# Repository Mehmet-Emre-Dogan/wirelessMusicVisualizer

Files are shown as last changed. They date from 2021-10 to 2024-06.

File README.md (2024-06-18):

# wirelessMusicVisualizer
Using two node MCU ESP8266 modules and addressable RGB LED strip, visualize the music, display animated flags, brighten the darkness (with the help of torch and emergency torch modes), and even Adalight compatible. Therefore, you can use it with any kind of Adalight compatible software, such as [Prismatik Unofficial](https://github.com/psieg/Lightpack)

# Abstract
**Purpose**: Measure the voltage level of the sound output of a device, i.e., computer, and send it to the receiver LED module via UDP protocol to visualize music.

## **Features**:
- Ability to change the used wi-fi channel to keep away interference
- Capable of saving the current configuration to external I2C EEPROM to avoid adjusting the settings on each boot
- Different colors and visualizing modes
- Software restart mode for transmitter
- Very low latency (no noticeable lag even with listening to music with wired headphones)
- Analog or serial data acquisition

## **Other Operating Modes**:
- Flag colored flowing light
- Ambiance light changing color according to the seen video on the computer screen
- Emergency light (with different tones of white)

## **Notes**:
- Both transmitter and receiver stations’ CPU frequency is set to 160 MHz to increase stability and smoothness
- Due to the nature of the UDP, sometimes packet drops occur. If the packet drops are incredibly high, changing the wi-fi channel is required. 

# Videos & Gifs of the project
<div align="center">
demoGif
<br>
</div>
<br>
The real project looks way smoother than the gif. You may watch the YouTube videos to see that. In fact, the actual refresh rate of the project is nearly 100 Hz; however, YouTube supports only up to 60 fps, and the gif is unfortunately only 30 fps.
<br>

- Please watch the [complete demonstration video](https://www.youtube.com/watch?v=xi880eUqIho) on YouTube.
- You may also want to watch my [playlist](https://www.youtube.com/playlist?list=PLV24y8ZhNEglrx4vv8YyNaVGACWpZlcM2) consisting of uncopyrighted music visualized by this project.

# Features
## Music visualization (Transmitter required)
- Smooth bar music visualizer in different color modes (steady gradient, flowing gradient, color shifting)
- Fast bar visualizer
- Brightness changing visualizer
- Optional music indicator and seconds indicator for all modes
## Torch (Transmitter required)
- Warm white light, 2700K color temperature.
- Optional seconds indicator
## Animated flags (Transmitter required)
- Display your county's flag colors on the RGB stick
- Not music reactive
## Emergency torch mode (nothing required) 
- Various colored lights in the color range 2700K to 6500K (press the red button once to change color)
- Adjustable brightness
- Optional seconds indicator (double press the red button to enable/disable seconds indicator)
## Adalight mode (USB micro type-B to type A cable required)
- Adalight client for Adalight compatible software

# Usage
## Connection with the transmitter station
Unpress the toggle switch first, then power up. If the transmitter station is near the receiver and turned on, the receiver will connect to the transmitter automatically and run according to the transmitter's configuration. 

## Audio sources for the transmitter station
### Analog
- Connect the 3.5mm audio jack to the audio source (PC/phone/tablet etc.) via y-splitter cable
- Select source as `analog` at the menu
### Serial
- Connect the transmitter station to a PC via USB cable.
- Install a client ( example: https://github.com/Mehmet-Emre-Dogan/vu-meter-with-serial ) to the PC to passthrough the audio signal from PC speaker/microphone to the transmitter station
- Select source as `serial` at the menu

## Enabling Adalight client mode
Press the toggle switch, adjust the potentiometer knob to the maximum, then power up the receiver. If you see the red, green, blue colors, respectively, the Adalight client mode has been initialized successfully.

## Enabling emergency torch mode
Press the toggle switch, and adjust the potentiometer below the maximum value, then power up. Note that the potentiometer is software inverted in the emergency torch mode so that the brightness increases when the potentiometer is rotated clockwise. (I did this because I was lazy to open the box again and swap the potentiometer positive and ground connections by desoldering and resoldering. I need to do the soldering job again because the purple cable has a jumper pin, but the blue one does not. The cables mentioned above can be seen on the image titled [Receiver station lid](#receiver-station-lid) ) 

## Changing modes
To your mode selection be valid, you need to restart the receiver station after adjusting the switch and the potentiometer. To restart, simply cut the power off and then back on.

## Browsing through the menu & changing the parameters
When the menu item title is highlighted, rotating the rotary encoder will change which setting you are about to change.
When a variable is highlighted, rotating the encoder will change the value of the variable.
Pressing the rotary encoder button will swap the selected item. For example, when the 'Brightness' is selected, if you press the encoder button, the brightness value will be selected to adjust the brightness of the LEDs.

## Saving the configuration
When you adjust the settings, move to 'saveConfig.' on the menu and press the rotary encoder button to write your current configuration to the external EEPROM.

# Necessary Libraries
Please install the libraries below if you have not done yet.
- [Fastled library](https://github.com/FastLED/FastLED)
- [Adafruit GFX library](https://github.com/adafruit/Adafruit-GFX-Library)
- [Adafruit SSD1306 library](https://github.com/adafruit/Adafruit_SSD1306)
- [SoftwareI2C library](https://github.com/Seeed-Studio/Arduino_Software_I2C)

# Schematics
## Transmitter
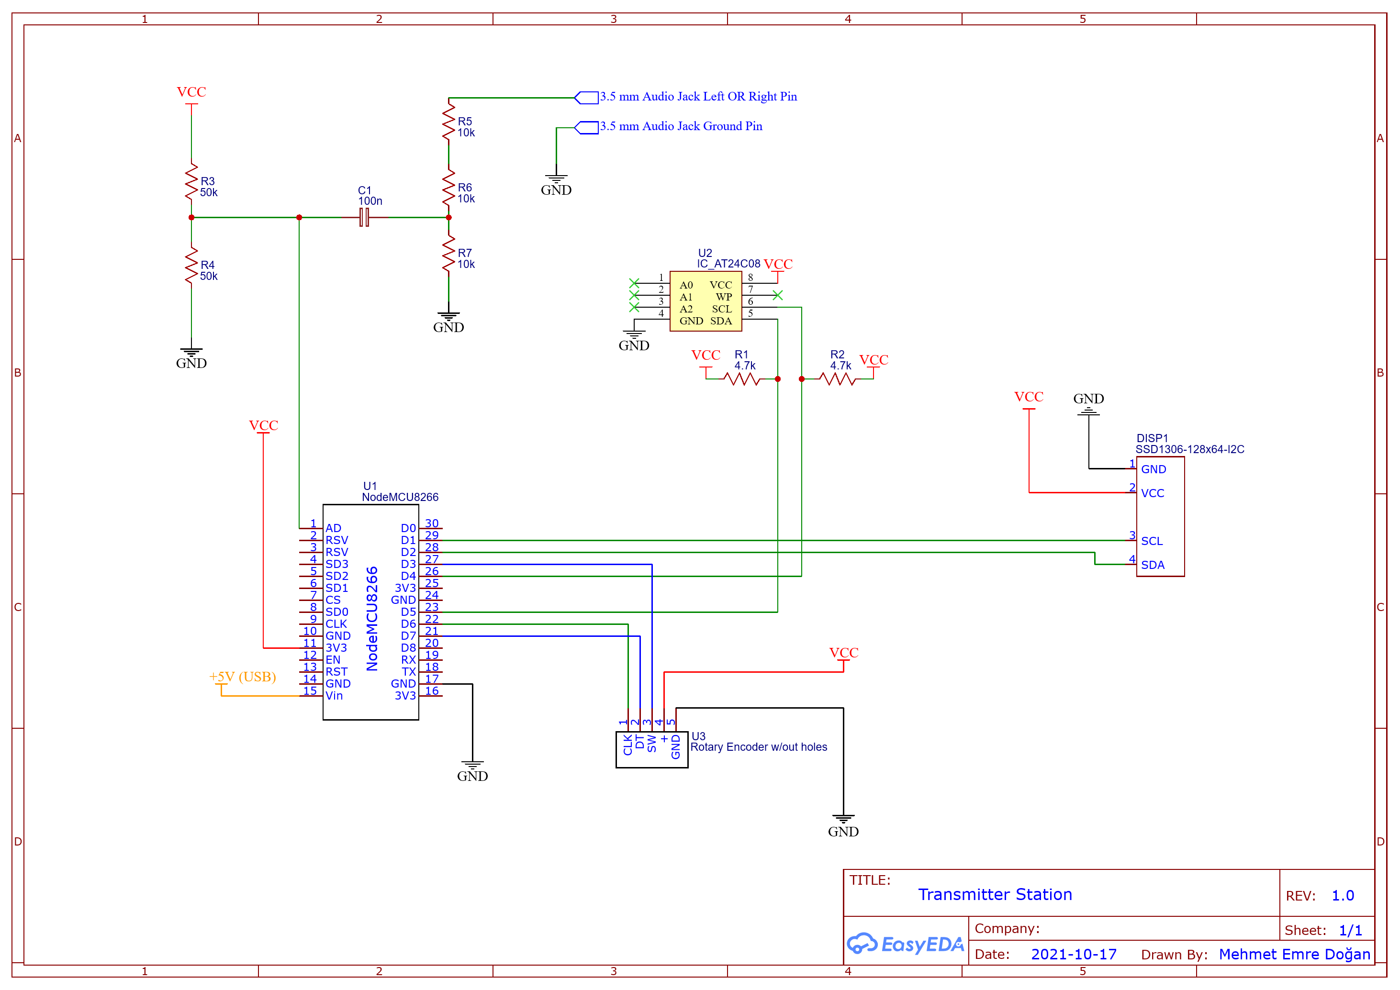
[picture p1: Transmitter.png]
Transmitter Schematic


## Receiver
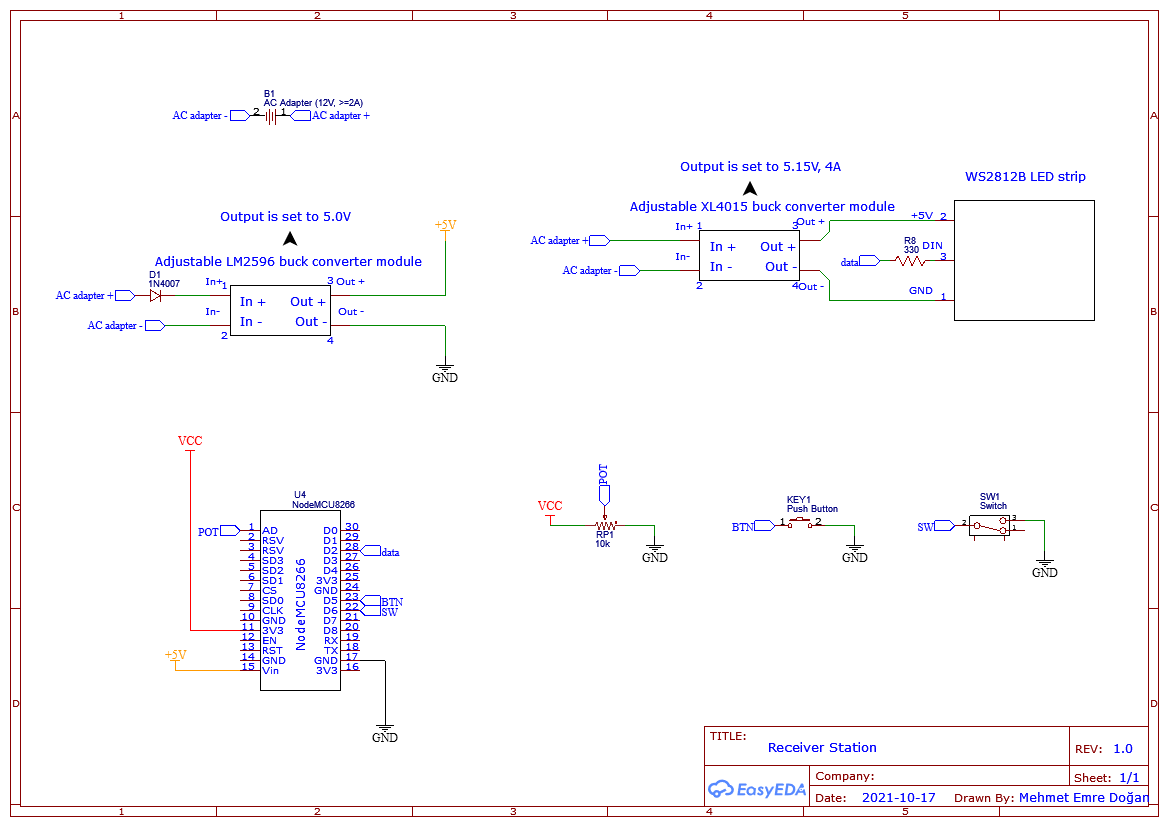
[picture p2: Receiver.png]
Receiver Schematic


# Pictures

## Transmitter
### Inside of the transmitter station
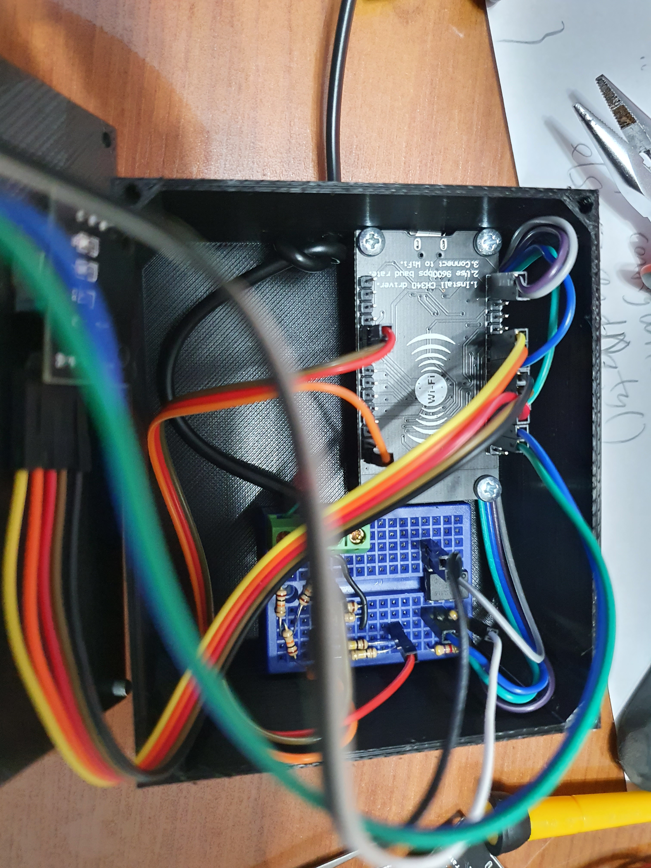
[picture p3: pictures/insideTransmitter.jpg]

### Transmitter station lid
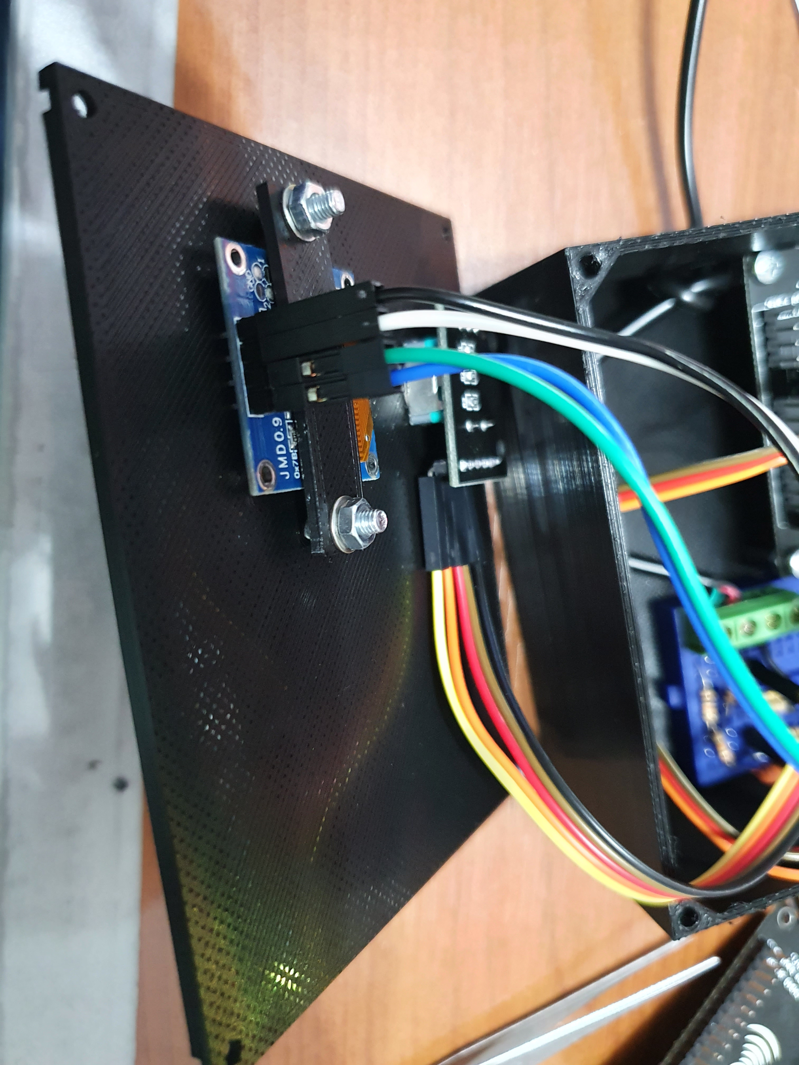
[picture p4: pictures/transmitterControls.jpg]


## Receiver
### Inside of the receiver station
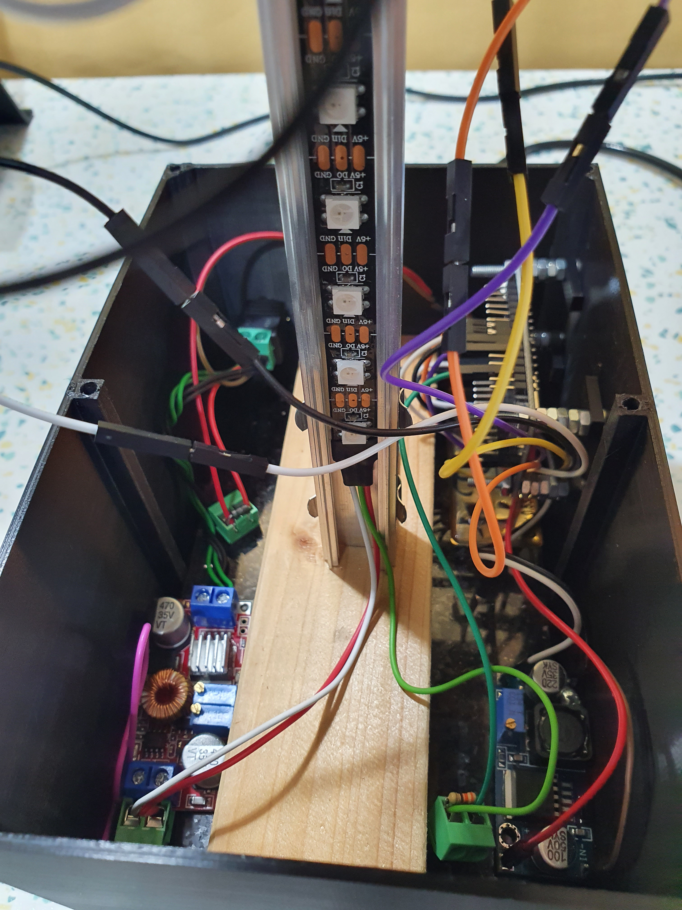
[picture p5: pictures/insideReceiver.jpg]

### Receiver station lid
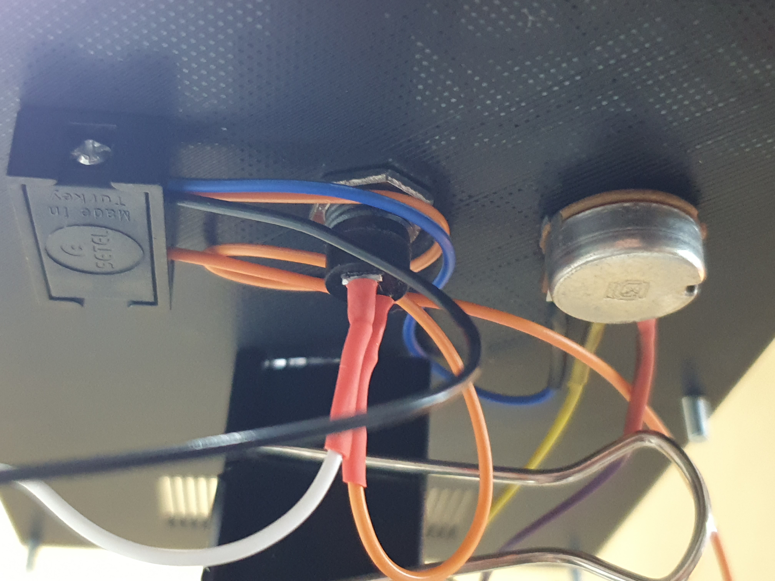
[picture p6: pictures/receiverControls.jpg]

### Adjustable XL4015 step down converter module
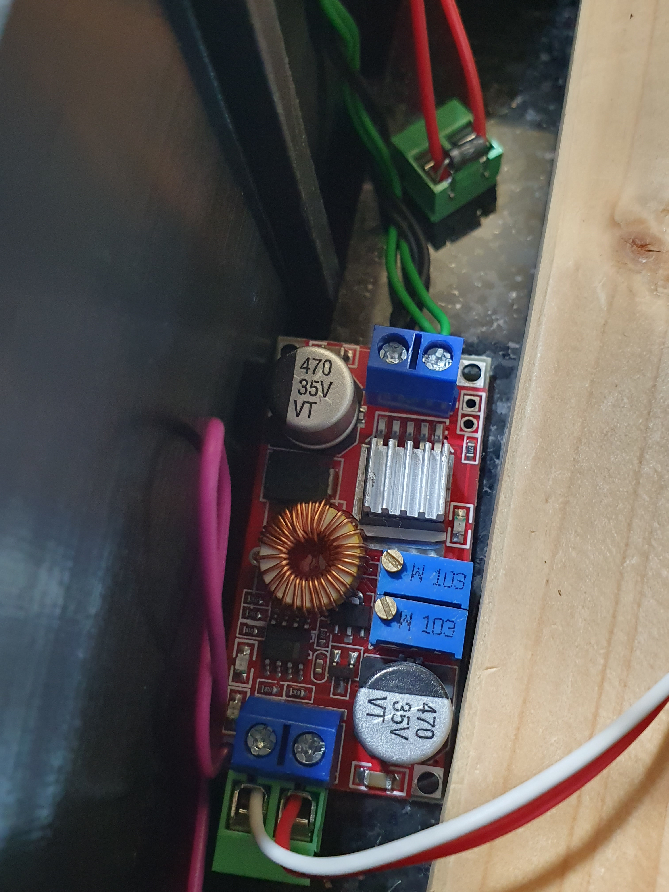
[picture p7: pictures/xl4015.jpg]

### Adjustable LM2596 step down converter module
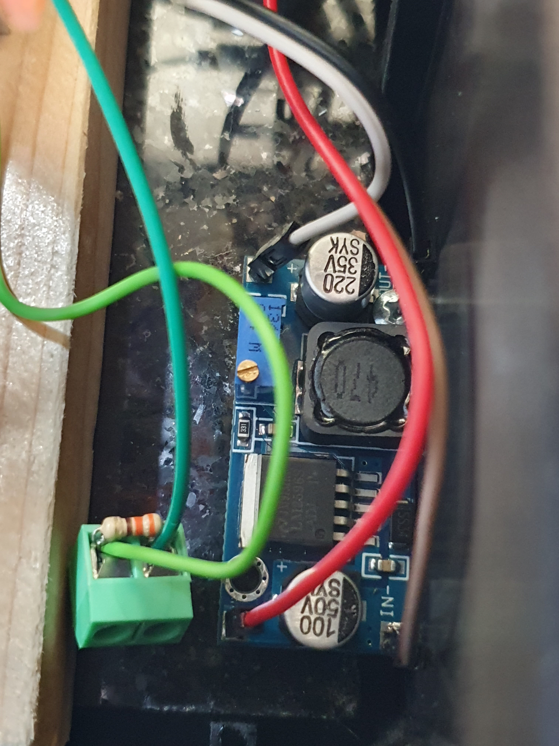
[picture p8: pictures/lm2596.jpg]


# Additional equipments
They are not directly related to the project. However, they are worth mentioning.

### Powering the device mobile or in mains power loss & failure
When necessary, the external boost converter module can be used to power the device via a power bank or any device that is powerful enough and has a USB out. Warning: You may need to decrease the brightness of the LEDs if your power gadget is not capable enough to run the device flawlessly. Most of the time, if you try to draw more current than your power gadget can handle, your power gadget will disconnect its battery from the output, and you will need to restart your power device. Sometimes, your power device can automatically do this restart process and cause the LEDs to flicker/blink. Therefore, if you face any abnormal behaviors like above mentioned, my advice is to decrease the brightness first (from the transmitter module or the potentiometer, in emergency torch mode) and then turn off and on the receiver station using the switch on the external boost converter module or directly plug out the USB cable and plug it in back.

### External XL6009 adjustable step-up converter module
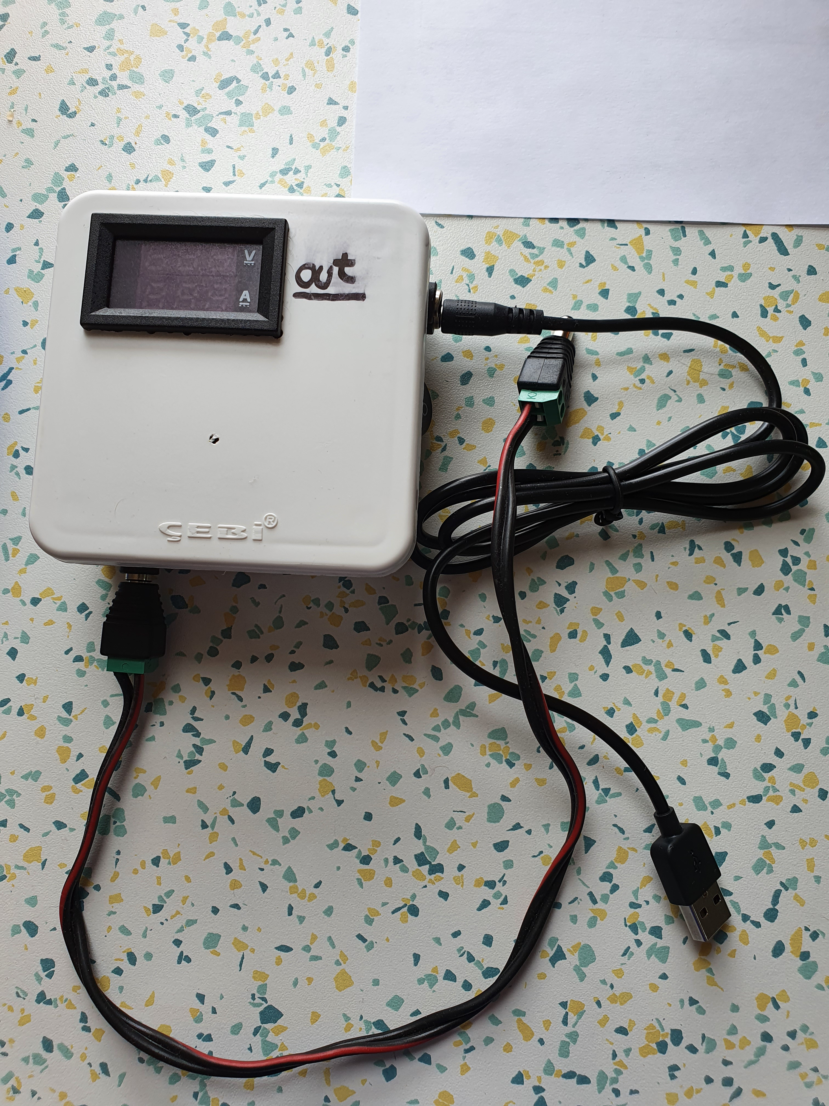
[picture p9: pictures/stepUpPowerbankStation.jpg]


### Inside of the adjustable XL6009 step-up converter module
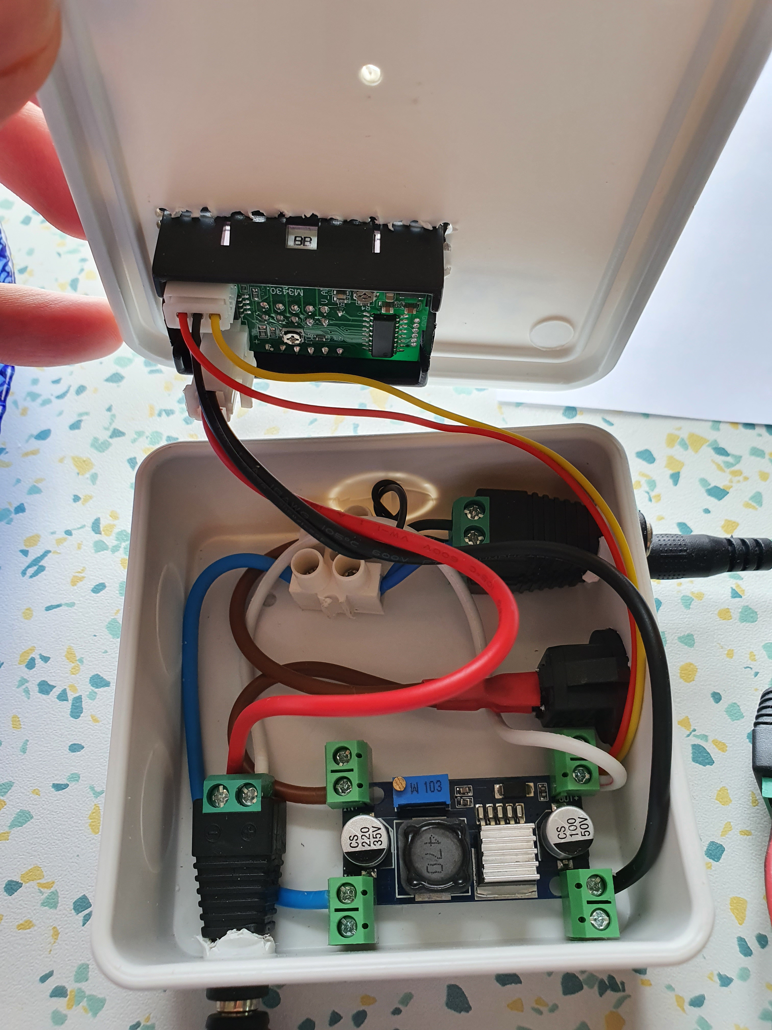
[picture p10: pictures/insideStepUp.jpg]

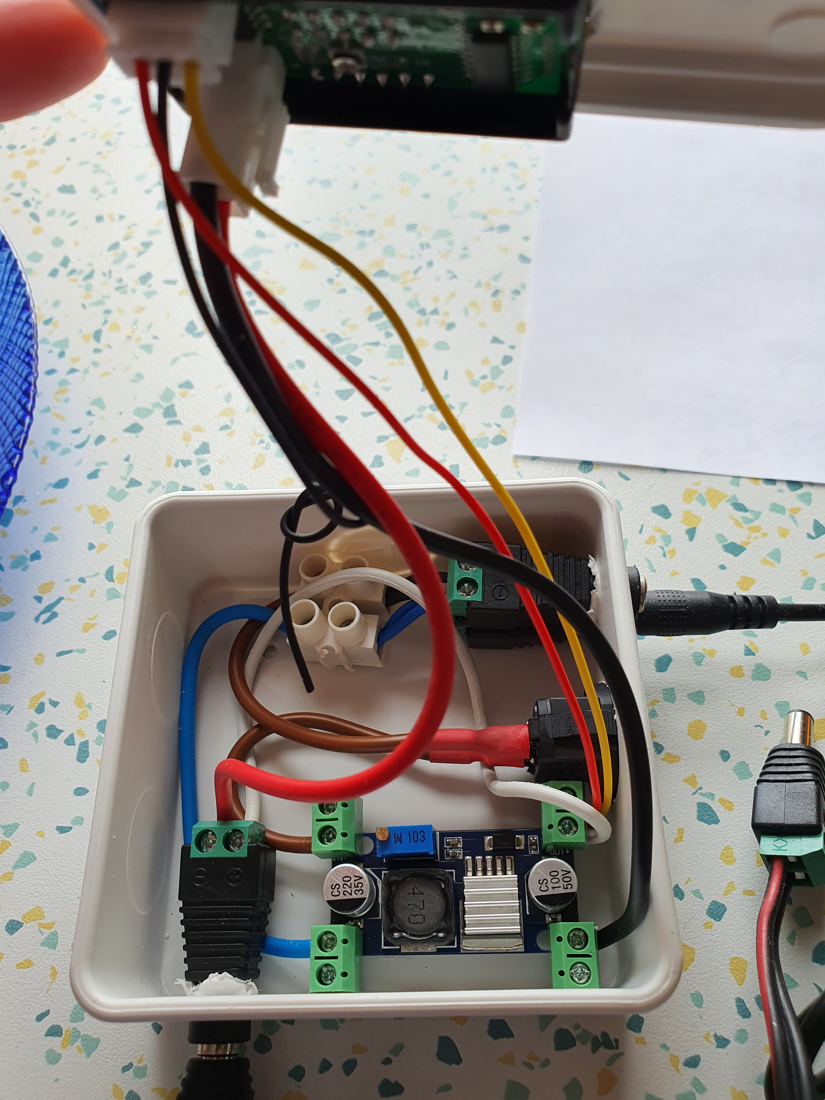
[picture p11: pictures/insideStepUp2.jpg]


### Input side of the adjustable XL6009 step-up converter module
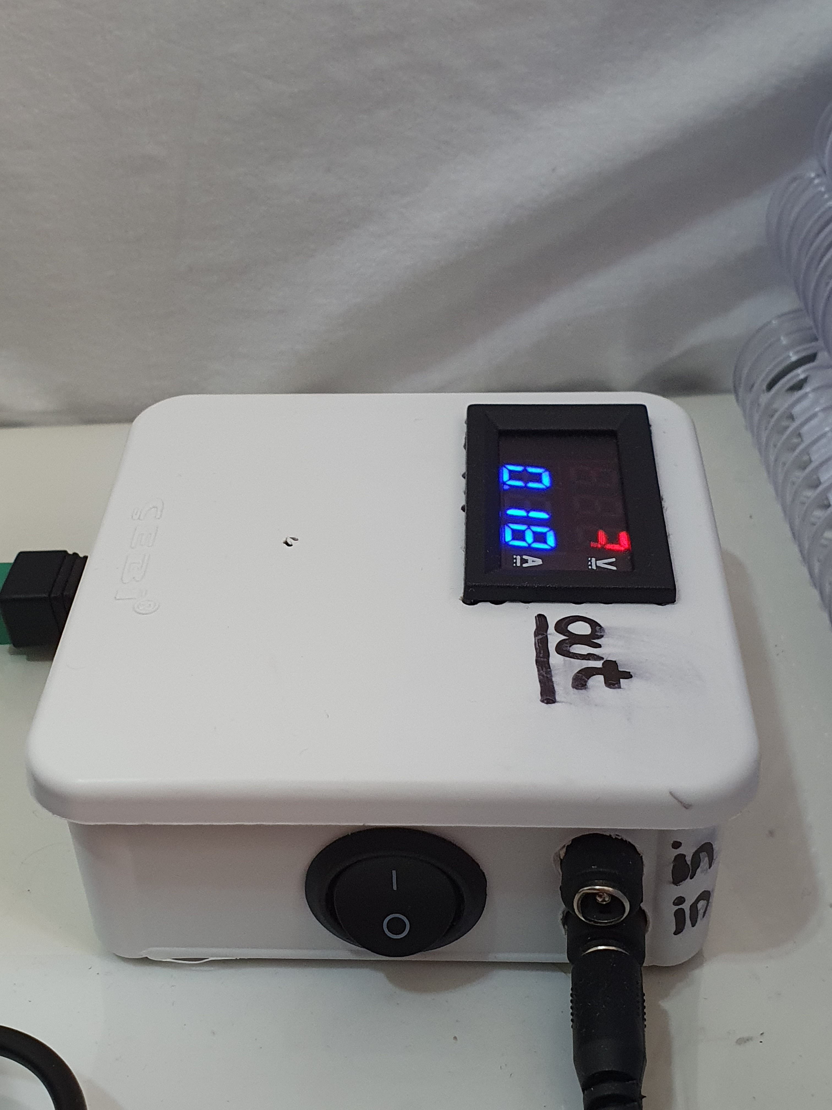
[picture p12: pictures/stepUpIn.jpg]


### Output side of the adjustable XL6009 step-up converter module
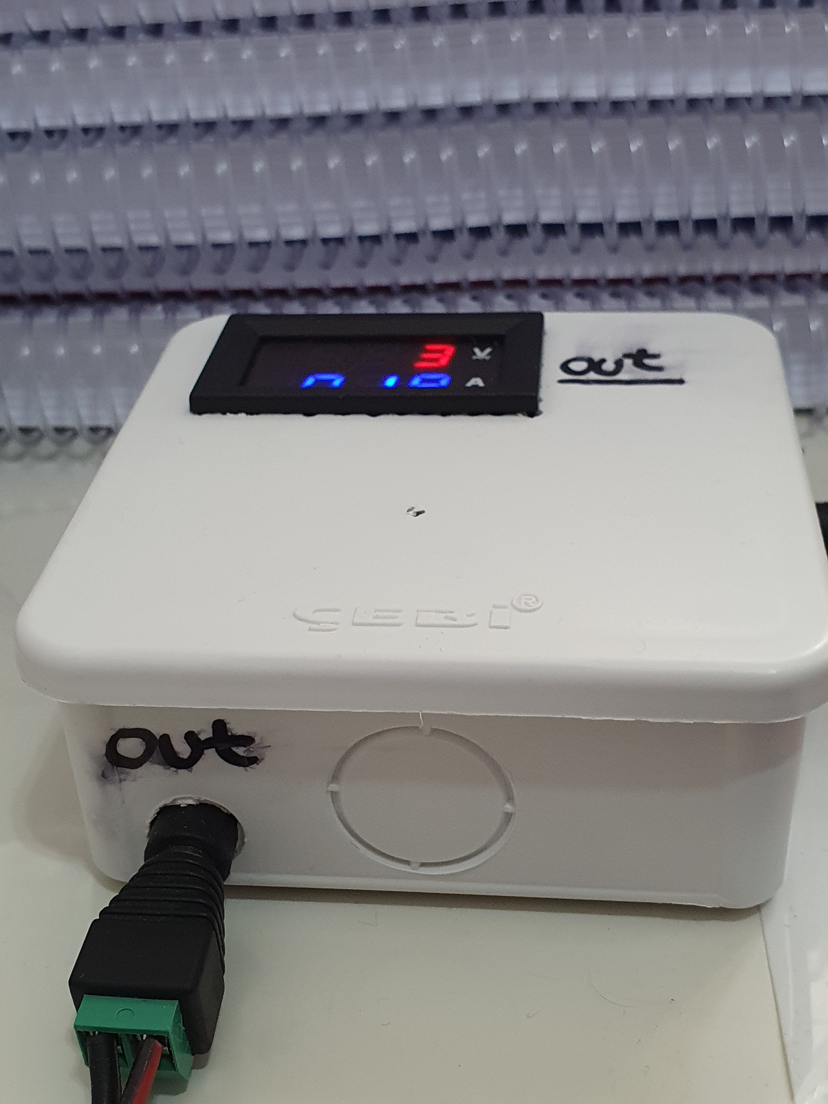
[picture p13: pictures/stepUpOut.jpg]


### Running on powerbank
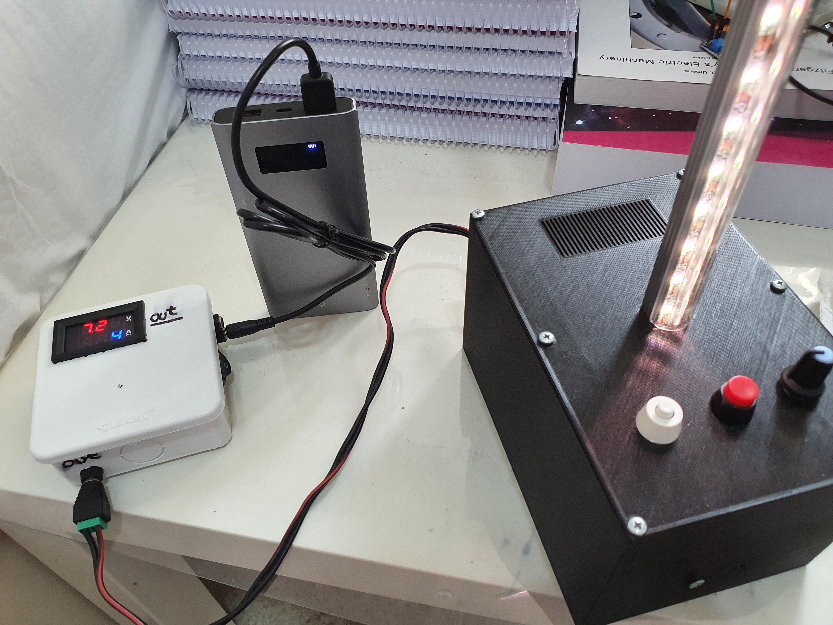
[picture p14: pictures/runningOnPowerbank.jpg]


### Attached voltmeter ampermeter combo device
Since the meter screen is multiplexing the seven-segment displays, in the above photos, the screen seems corrupted. However, this is not the case. By the way, with the naked eye, this multiplexing is not noticeable as expected.



## Recording setup
The setup to record line output of the PC with any mobile phone.
There is a 10 kOhm resistor between any signal output channel, left or right, to mobile phone microphone input.

### Y cable to split recording setup and my project (transmitter station + headphones, which also uses another Y cable)
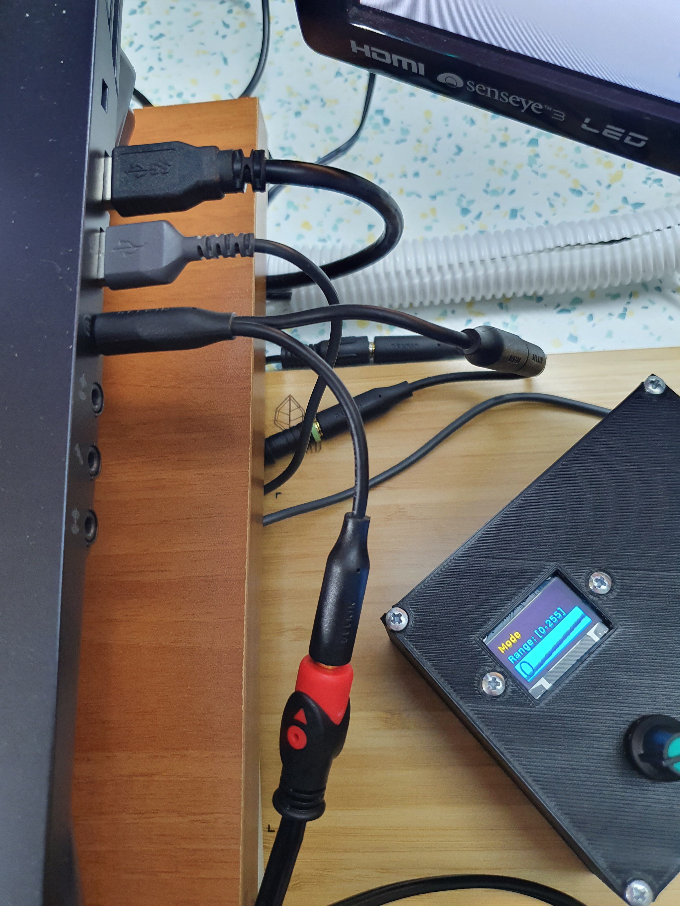
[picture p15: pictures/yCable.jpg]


### Recording setup
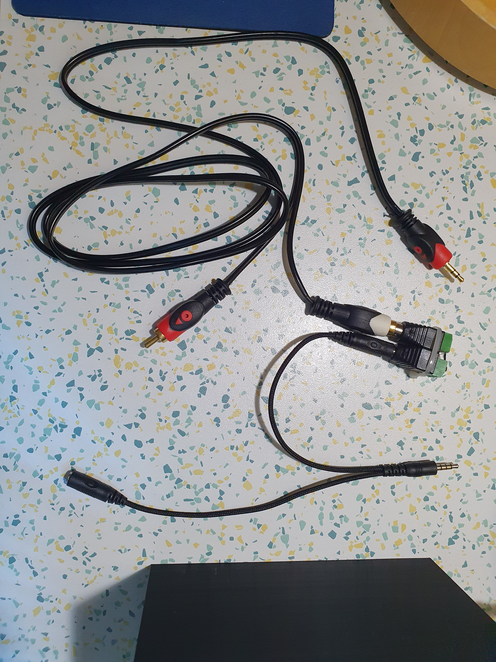
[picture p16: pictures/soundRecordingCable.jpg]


### 10 kOhm resistor close up
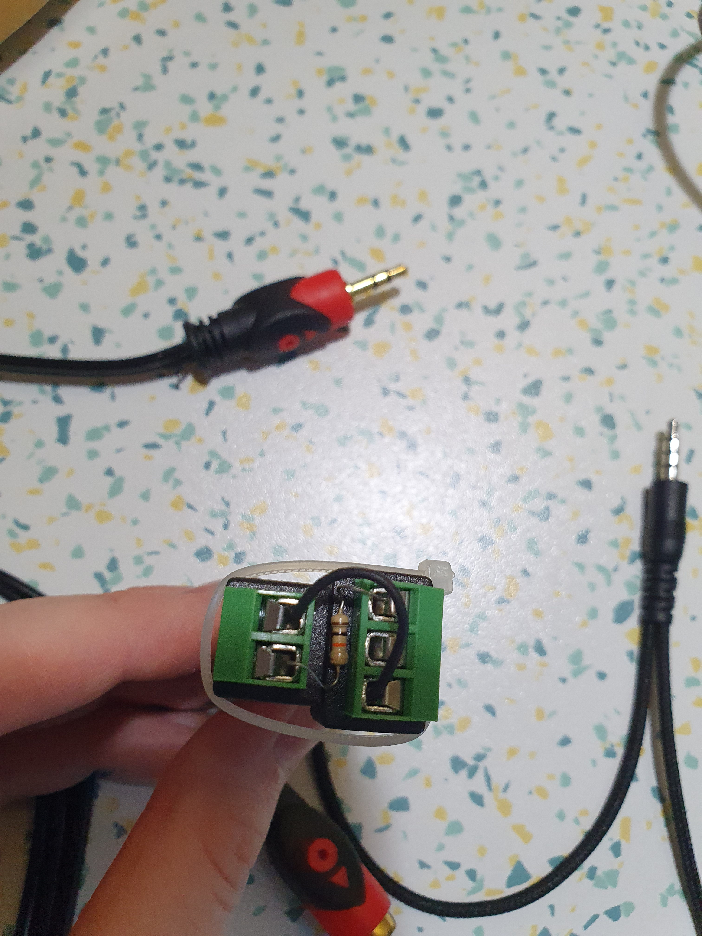
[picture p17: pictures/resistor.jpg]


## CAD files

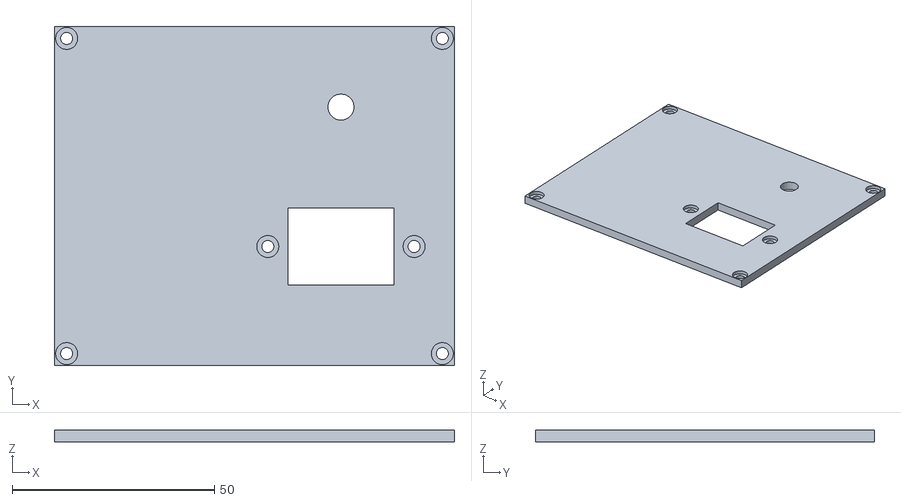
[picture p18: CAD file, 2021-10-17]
3d designs/transmitterLid.stl
99.0 x 84.0 x 3.00

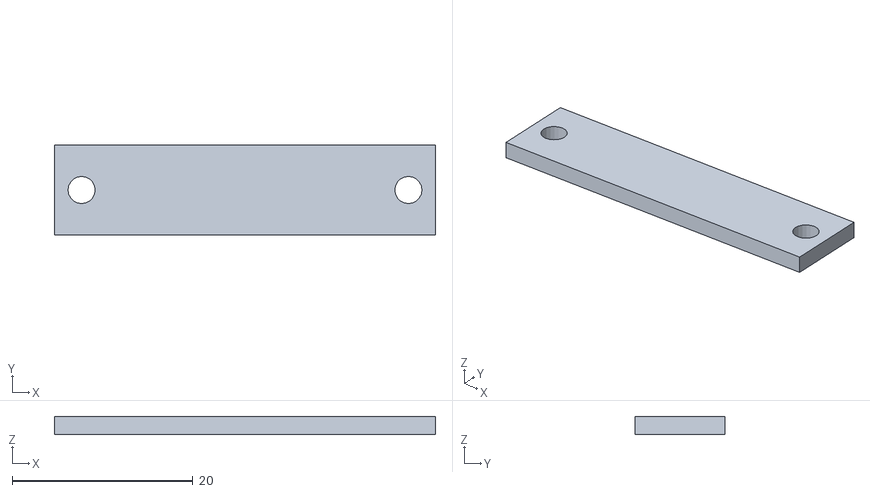
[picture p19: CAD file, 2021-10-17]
3d designs/screenApparatus.stl
42.2 x 10.0 x 2.00

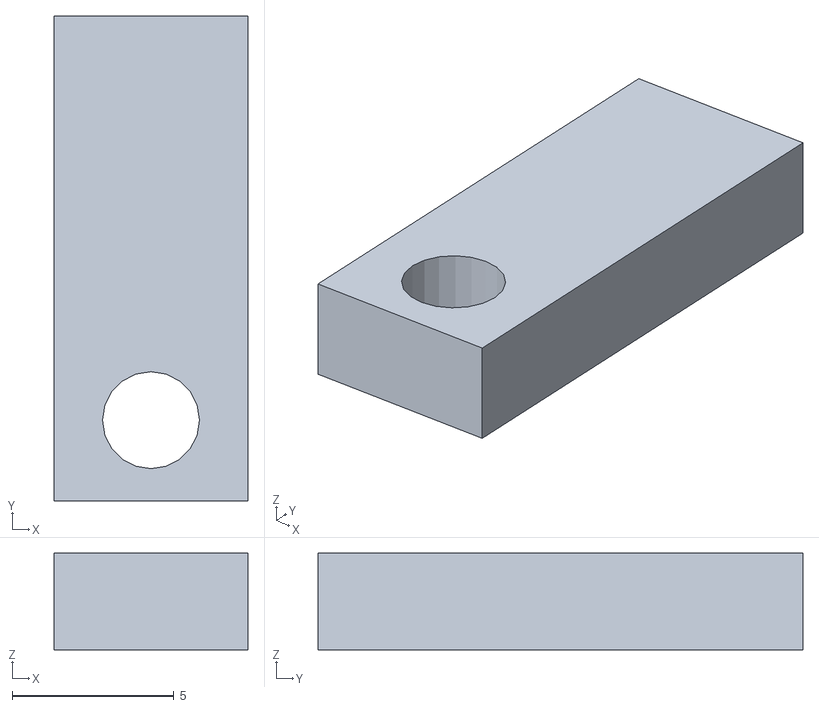
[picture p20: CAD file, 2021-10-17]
3d designs/marbleThing.stl
6.00 x 15.0 x 3.00

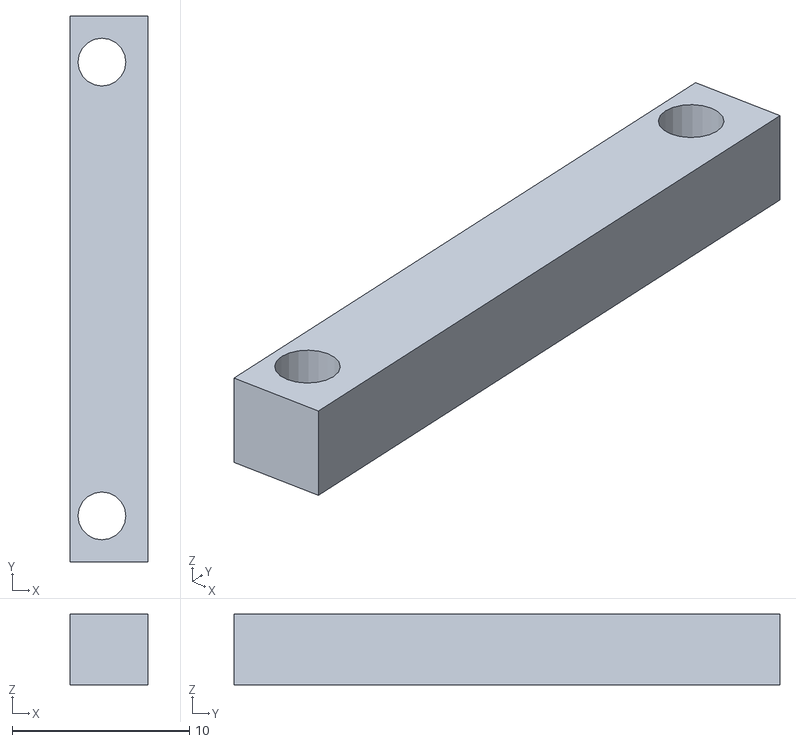
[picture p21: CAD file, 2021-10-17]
3d designs/nodeApparatus.stl
4.40 x 30.8 x 4.00

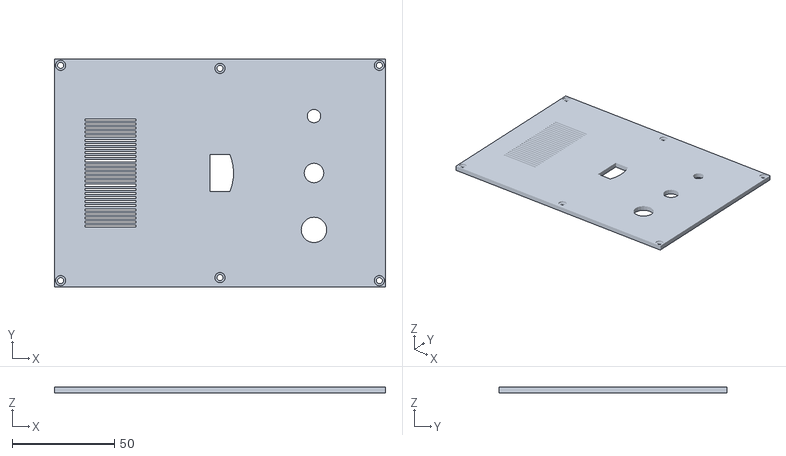
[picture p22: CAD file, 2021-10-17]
3d designs/receiverLid.stl
162.0 x 111.4 x 3.00

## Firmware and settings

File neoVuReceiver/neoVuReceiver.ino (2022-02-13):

/******** References *********/
/* 
 *  ============= Disabling wifi =============
 *  https://www.esp8266.com/viewtopic.php?p=72207
 *  
 *  ============= Animated Flag ============= 
 * https://www.youtube.com/watch?v=2owTxbrmY-s&list=PLgXkGn3BBAGi5dTOCuEwrLuFtfz0kGFTC&index=4
 * https://github.com/s-marley/FastLED-basics/blob/main/4.%20Waves%20and%20blur/phaseBeat/phaseBeat.ino
 * 
 * ============= Adalight =============
 * https://github.com/Wifsimster/adalight_ws2812/blob/master/Adalight_WS2812.ino
 * 
 */
#define FASTLED_ESP8266_RAW_PIN_ORDER
/* Libraries */
#include <FastLED.h>
#include <ESP8266WiFi.h>
#include <WiFiUDP.h>

/* Misc */
#define DEBUG_ENABLED false // Disable debug to be able to use the Adalight mode
#include "secrets.h"

/******** Constants *********/
#define EMERGENCY_TORCH_NUM 4
#define BUTTON_CONSIDERATION_LIMIT 50 // if the consequent button presses are less than it; ignore last press
#define BUTTON_DOUBLE_PRESS_TIMEOUT 120
#define BUTTON_MAX_PRESS_COU 2
#define CONNECTION_LOST_TIMEOUT 10000
#define ARRAY_SHIFT_INTERVAL 9
#define COLOR_SHIFT_INTERVAL 1

/* Display */
#define INDICATOR_OFFSET 5
#define DECAY_INTERVAL 9
#define INDICATOR_ITER_LIM 20
#define CRITICAL_LEVEL 5

/* Leds */
#define DATA_PIN D2
#define NUM_LEDS 58
#define LED_TYPE WS2812B
#define COLOR_ORDER GRB

/* Drop width modulation mode */
#define DIVIDER 6
#define MAX_WIDTH 10 //NUM_LEDS/DIVIDER
#define EMPTY_WIDTH 30
//#define DWM_MEAS_LIM 5 // Drop width modulation measurement count
#define DROP_INTERVAL 4

/* Serial communication */
#define ADA_RATE 1000000 // Baud rate for Adalight mode 
#define DEBUG_RATE 9600 // Baud rate to print debug info to computer

/* Physical ui elemets */
#define BTN D5
#define SWITCH D6
#define POT A0

/******** Function templates ********/
void ICACHE_RAM_ATTR handleBtn();


/* Global variables */
byte physicalMode = 0; // Using the switch, button, and tyhe potentiometer on the module, decide which mode to execute
unsigned long lastPressTime = 0;
byte pressCou = 0;

const char delim[2] = ":";

int measurementRes = 0; // stores the raw measurement value
byte brightness = 127;
byte currMode = 0; // current mode
byte prevMode = 0; // previous mode
byte measurementCoeff = 4; // Scales the measurement // i.e. sensivity
bool musicIndicatorEnabled = true; 
bool indicateSeconds = true; // Whether the seconds being indicated

//byte threshold = 0; // ignore values below
//int prevMeasurementRes = 0; // previous measurement value

bool isThisMaxFirst = false; // whether measurement max value was reached previously

int ledLevel = 0; // current height of the led bar
int maxVal = 0; // reached maximum led level
int prewIndicatorLevel = 0;

byte numberOfItersInd = 0; // Number of iterations of indicator drawer

unsigned long prewDecayTime = 0; 
unsigned long prewIndicatorDecayTime = 0;

// 4294967295; // 2^32 - 1
unsigned long lastConnectionTime = 0;

//Array shifter
unsigned long lastArrayShift = 0;

//Color shifter
uint8_t minG = 0;
uint8_t minB = 0;
byte gbShiftMode = 0;
uint8_t G = 255;
uint8_t B = 255;
unsigned long lastColorShift = 0;

//Drop Width Modulation
unsigned long prevDropTime = 0;
byte dwmMode = 0; // Necessary to provide correct run order of the codes
int dwmIterator = 0; // Iterator to imitate outer for loop
int outputDwm = 0; // Will be our final result
int dwmMeasCou = 0; // How many measurements taken so far

CRGB secsIndicatorCol = CRGB(154, 205, 16); // seconds indicator color
CRGB IndicatorCol = CRGB::White; // music indicator color

CRGB leds[NUM_LEDS];
CRGB filled[NUM_LEDS];
CRGB buff[MAX_WIDTH];
CRGB buffFilled[MAX_WIDTH];

WiFiUDP UDP;
char packetBuffer[255]; //buffer to hold incoming packet

/* Color palettes */

DEFINE_GRADIENT_PALETTE( pal1 ) {
    0, 0,  255,  255, 
  255, 0, 255, 0};

DEFINE_GRADIENT_PALETTE( pal2 ) {
    0, 0,  255,  0, 
  255, 255, 0, 0};
  
DEFINE_GRADIENT_PALETTE( pal3 ) {
  0, 0, 255, 0,
  64, 0, 255, 255,
  127, 0, 255,  0,
  192, 0, 255, 255, 
  255, 0, 255, 0};
  
DEFINE_GRADIENT_PALETTE( pal4 ) {
  0, 0, 255, 0,
  255, 0, 255, 0};

DEFINE_GRADIENT_PALETTE( pal5 ) {
  0, 50, 255, 50,
  255, 50, 255, 50};

DEFINE_GRADIENT_PALETTE( pal6 ) {
  0, 255, 255, 255,
  255, 255, 255, 255};

DEFINE_GRADIENT_PALETTE( pal7 ) {
  0, 255, 255, 0,
  255, 255, 255, 0};

CRGBPalette16 palArr[] = {pal1, pal1, pal2, pal2, pal5, pal7, pal3, pal3, pal1, pal2, pal1, pal2, pal4, pal5, pal6, pal6};
CRGB IndicatorColors[] = {CRGB(255,128,0), CRGB::White, CRGB(0,0,128), CRGB::White, CRGB::Green, CRGB::Red, CRGB::White, CRGB::White, CRGB::White, CRGB::White,  CRGB::White, CRGB::White, CRGB::White, CRGB::Green, CRGB::White, CRGB::Red};
CRGB secsIndicatorColors[] = {CRGB::Yellow, CRGB::Yellow, CRGB::Cyan, CRGB::Cyan, CRGB::White, CRGB::Green, CRGB(255,128,0), CRGB(255,128,0), CRGB::White, CRGB::White, CRGB::White, CRGB::White, CRGB(255,128,0), CRGB::White, CRGB::Red, CRGB(100,20,100)};

void setupWifi(){
  WiFi.disconnect(); //Disconnect from old connections
  WiFi.begin(MY_SSID, PASSWORD);
  WiFi.mode(WIFI_STA); // Only connect the router
  while (WiFi.status() != WL_CONNECTED) { //Loop here until connected
    digitalWrite(LED_BUILTIN, LOW);
    delay(400);
    digitalWrite(LED_BUILTIN, HIGH);                
    delay(100);
    // For delay, 500 ms in total is good. Splitting it to 400 + 100 enables us to see blinking LED                          
  }
  WiFi.config(receiverIP, subnet, gateway, dns); // Configure Wifi settings
  
  UDP.begin(UDP_RESPONSE_PORT);
  UDP.beginPacket("192.168.4.1", UDP_REQUEST_PORT); //send ip to server
  UDP.write("i"); // "i" for init, i.e. request all variables available
  UDP.endPacket();
}

void disableWifi(){
  WiFi.disconnect(); //Disconnect from old connections
  WiFi.mode(WIFI_OFF);
  WiFi.forceSleepBegin();
}

void painter(){
  if (currMode >= 16){
    prevMode = currMode;
    return;
  }
     
  fill_palette(filled, NUM_LEDS, 0, 255 / NUM_LEDS, palArr[currMode], 255, LINEARBLEND);
  secsIndicatorCol = secsIndicatorColors[currMode];
  IndicatorCol = IndicatorColors[currMode];
  
  byte gbShiftMode = 0;
  uint8_t G = 255;
  uint8_t B = 255;
  unsigned long lastColorShift = 0;

  fill_palette(buffFilled, MAX_WIDTH, 0, 255 / MAX_WIDTH, palArr[currMode], 255, LINEARBLEND);
  dwmMode = 0;
  
  prevMode = currMode;
}

void setIOMode(){
  pinMode(POT,INPUT);
  pinMode(SWITCH,INPUT_PULLUP);
  pinMode(BTN, INPUT_PULLUP);
  attachInterrupt(digitalPinToInterrupt(BTN), handleBtn, FALLING); 
}

void decidePhysMode(){
  if(digitalRead(SWITCH))
    physicalMode = 0;
  else if (analogRead(POT) < 1022)
    physicalMode = 1;
  else
    physicalMode = 2;
}

void setup() {
  if (DEBUG_ENABLED){
    Serial.begin(DEBUG_RATE);
  }
  
  setIOMode();
  FastLED.addLeds<LED_TYPE, DATA_PIN, COLOR_ORDER>(leds, NUM_LEDS);
  //FastLED.setTemperature(Tungsten40W);

  decidePhysMode();
  if (!physicalMode){
    setupWifi();
    painter();
  }
  else{
    disableWifi();
  }

  if (physicalMode == 2){// Start Adalight
    // Initial RGB flash
    LEDS.showColor(CRGB(255, 0, 0));
    delay(500);
    LEDS.showColor(CRGB(0, 255, 0));
    delay(500);
    LEDS.showColor(CRGB(0, 0, 255));
    delay(500);
    LEDS.showColor(CRGB(0, 0, 0));
    
    Serial.begin(ADA_RATE);
    Serial.print("Ada\n");
  }

}

void handleRemoteMode(){
  receiveData();
  if (prevMode != currMode)
    painter();
  FastLED.setBrightness(brightness);
  
  if (0 <= currMode && currMode <= 5){
    drawVuSmooth(musicIndicatorEnabled, IndicatorCol); // drawVuSmooth(bool indicatorEnabled, CRGB indicatorColor)
  }
  else if (currMode == 6){
    arrayShifter(1);
    drawVuSmooth(musicIndicatorEnabled, IndicatorCol); // drawVuSmooth(bool indicatorEnabled, CRGB indicatorColor)
  }
  else if (currMode == 7){
    arrayShifter(0);
    drawVuSmooth(musicIndicatorEnabled, IndicatorCol); // drawVuSmooth(bool indicatorEnabled, CRGB indicatorColor)    
  }
  else if (8 <= currMode && currMode <= 9){
    dropWidthModulation();
  }
  else if (10 <= currMode && currMode <= 11){
    drawVuFast();
  }
  else if (currMode == 12){
    colorShifter();
    drawVuSmooth(musicIndicatorEnabled, IndicatorCol); // drawVuSmooth(bool indicatorEnabled, CRGB indicatorColor)
  }
  else if (13 <= currMode && currMode <= 14){
    pwmVu();
  }
  else if (currMode == 15){
    torch(CRGB(255, 150, 40));
  }
  else if (16 <= currMode && currMode <= 17){
    animatedFlag(currMode);
  }
}

void handleBtn(){
  if (DEBUG_ENABLED)
    Serial.println("Button pressed");
  
  delay(10);
  while(!digitalRead(BTN)) // wait until the btn released
    delay(2);

  if ( (millis() - lastPressTime) >= BUTTON_CONSIDERATION_LIMIT ){// i.e. button intentionally pressed
    pressCou++;
    lastPressTime = millis();
  }
}

void emergencyTorch(){
  FastLED.setBrightness((1023 - analogRead(POT))/4);

  if (pressCou){
    while( (millis() - lastPressTime) < BUTTON_DOUBLE_PRESS_TIMEOUT) //wait for second or more presses
      ;
  }

  if (pressCou >= BUTTON_MAX_PRESS_COU)
    pressCou = BUTTON_MAX_PRESS_COU;

  switch(pressCou){
  case 1:
    currMode++;
    currMode %= EMERGENCY_TORCH_NUM;
    pressCou = 0;
    break;
  case 2:
    indicateSeconds = !indicateSeconds; // toggle
    pressCou = 0;
    break;
  default:
    ;
}




  switch(currMode){ 
    case 3:
      torch(CRGB(255, 255, 255));
      break;
    case 2:
      torch(CRGB(255, 255, 220));
      break;
    case 1:
      torch(CRGB(255, 220, 127));
      break;
    case 0:
      torch(CRGB(255, 150, 40));
      break;
    default:
      ;
    }

  /*if (DEBUG_ENABLED){
    Serial.print("Emergency Torch Mode: ");
    Serial.println(currMode);
  }*/

}


void handleAdalight(){
  uint8_t prefix[] = {'A', 'd', 'a'}, hi, lo, chk, i;
  
  // Wait for first byte of Magic Word
  for(i = 0; i < sizeof prefix; ++i) {
    waitLoop: while (!Serial.available()) ;;
    // Check next byte in Magic Word
    if(prefix[i] == Serial.read()) continue;
    // otherwise, start over
    i = 0;
    goto waitLoop;
  }
  
  // Hi, Lo, Checksum  
  while (!Serial.available()) ;;
  hi = Serial.read();
  while (!Serial.available()) ;;
  lo = Serial.read();
  while (!Serial.available()) ;;
  chk = Serial.read();
  
  // If checksum does not match go back to wait
  if (chk != (hi ^ lo ^ 0x55)) {
    i = 0;
    goto waitLoop;
  }
  
  memset(leds, 0, NUM_LEDS * sizeof(struct CRGB));
  // Read the transmission data and set LED values
  for (uint8_t i = 0; i < NUM_LEDS; i++) {
    byte r, g, b;    
    while(!Serial.available());
    r = Serial.read();
    while(!Serial.available());
    g = Serial.read();
    while(!Serial.available());
    b = Serial.read();
    leds[i].r = r;
    leds[i].g = g;
    leds[i].b = b;
  }
  
  // Shows new values
  FastLED.show();
}

void loop(){
  switch(physicalMode){
    case 0:{
      handleRemoteMode();
      break;
    }
    case 1:{
      emergencyTorch();
      break;
    }
    case 2:{
      handleAdalight();
      break;
    }
    default:
      ;   
  }
}

void receiveData(){
  UDP.parsePacket();
  UDP.beginPacket("192.168.4.1", UDP_REQUEST_PORT); //send ip to server
  UDP.write("1");
  UDP.endPacket();
  int len = UDP.read(packetBuffer, 255);
  char *subs = "empty";
  if (len > 0) {
      if (DEBUG_ENABLED){
    Serial.println(packetBuffer);
   }
    packetBuffer[len] = 0;   
    subs = strtok(packetBuffer, delim);
    measurementRes = rescale(atoi(subs) * measurementCoeff);
    subs = strtok(NULL, delim);
    brightness = (byte) atoi(subs);
    subs = strtok(NULL, delim);
    currMode = (byte) atoi(subs);
    subs = strtok(NULL, delim);
    measurementCoeff = (byte) atoi(subs);
    subs = strtok(NULL, delim);
    musicIndicatorEnabled = (bool) atoi(subs);
    subs = strtok(NULL, delim);
    indicateSeconds = (bool) atoi(subs);

    lastConnectionTime = millis();
  }
  else{
    // If connection is lost for a while, then asign measurementRes = 0 to let the LED decay
    if( millis() - lastConnectionTime > CONNECTION_LOST_TIMEOUT){
      measurementRes = 0;
      lastConnectionTime = millis();
    }
    String myStr = "EMPTY";
    myStr.toCharArray(packetBuffer, 35);
  }

}

int rescale(int res){
  res = map(res, 0, 512, 0, (NUM_LEDS+1));
  if (res >= NUM_LEDS-1)
    res = NUM_LEDS-1;
  return res;
}

void drawVuSmooth(bool indicatorEnabled, CRGB indicatorColor){
  if (measurementRes >= ledLevel){
    ledLevel = measurementRes;
  }

  else{
    if ( ( (millis() - prewDecayTime) >= DECAY_INTERVAL ) && ledLevel>(measurementRes)){
      ledLevel--;
      prewDecayTime = millis();
    }
  }
  FastLED.clear();
  for(int i=0; i < ledLevel; i++){
    leds[i] = filled[i];
  }
  if (indicatorEnabled)
    drawIndicator(ledLevel, indicatorColor);
  if(indicateSeconds)
    leds[(millis()/1000)%NUM_LEDS] = secsIndicatorCol;
 
  FastLED.show();
  
  //prevMeasurementRes = measurementRes;
}

void drawIndicator(int value, CRGB color){
  if (value+1 >= maxVal && value > CRITICAL_LEVEL && value > prewIndicatorLevel){
    maxVal = value;
    isThisMaxFirst = true;
    numberOfItersInd = 0;
  }

  if (isThisMaxFirst && ( (millis() - prewIndicatorDecayTime) >= DECAY_INTERVAL )){
      maxVal += 1;
      prewIndicatorDecayTime = millis();
      numberOfItersInd++;      
  }
  else if ( ( (millis() - prewIndicatorDecayTime) >= DECAY_INTERVAL*1.3 && !isThisMaxFirst && value+1 <= maxVal)){
      maxVal -= 1;
      prewIndicatorDecayTime = millis();
    }
    
  if (numberOfItersInd >= INDICATOR_ITER_LIM){
    isThisMaxFirst = false; 
  }
  prewIndicatorLevel = maxVal;
  
  if (maxVal > CRITICAL_LEVEL){
    if (maxVal < (NUM_LEDS))
      leds[maxVal] = color;
    if (maxVal < (NUM_LEDS-1))
      leds[maxVal+1] = color;
    if (maxVal < (NUM_LEDS-2))
      leds[maxVal+2] = color;
  }
  else
    return;
}

void arrayShifter (bool shiftUp){
  if(millis() - lastArrayShift >= ARRAY_SHIFT_INTERVAL){
    if(shiftUp){
      CRGB holder = filled[NUM_LEDS-1];
      for(int i = NUM_LEDS-1; i > 0; i--){
        filled[i] = filled[i-1];
      }
      filled[0] = holder;
    }
    else{
      CRGB holder = filled[0];
      for( int i = 0; i < (NUM_LEDS-1); i++){
        filled[i] = filled[i+1];
      }
      filled[NUM_LEDS-1] = holder;
    } 
  lastArrayShift = millis();
  }
}

void colorShifter(){
  if(millis() - lastColorShift >= COLOR_SHIFT_INTERVAL){
    switch (gbShiftMode){
      case 0:
        G -= 1;
        if (G == minG)
        gbShiftMode = 1;
        break;
      case 1:
        G += 1;
        if (G == 255)
          gbShiftMode = 2;
        break;
      case 2:
        B -= 1;
        if (B == minB)
        gbShiftMode = 3;
        break;
      case 3:
        B += 1;
        if (B == 255)
        gbShiftMode = 0;
        break;
      default:
        ;
    }
  lastColorShift = millis();
  fill_solid(filled, NUM_LEDS, CRGB(0, G, B));
  }
}

void accumulateMeasurementsForDwm(){
  outputDwm += measurementRes;
  dwmMeasCou++;
}

void dropWidthModulation(){
  if( (millis() - prevDropTime) >= DROP_INTERVAL ){
    switch (dwmMode){
      case 0:{
        int output = 0;
        if (dwmMeasCou) // if dwmMeasCou is not 0
          output = outputDwm/dwmMeasCou/DIVIDER;
          
        // Clear buffer
        for(int i = 0; i < MAX_WIDTH; i++){ 
          buff[i] = CRGB::Black;
        }
        // Fill buffer until output value reached
        for(int i = 0; i < (output); i++){
          buff[i] = buffFilled[i];
        }
        
        // clear variables
        outputDwm = 0;
        dwmMeasCou = 0;
        dwmMode = 1;
        dwmIterator = 0;
        break;
      }
    
      // Write buffer to leds while shifting the old outputs
      case 1:{
        for(int i = 0; i < (NUM_LEDS - 1); i++){
          leds[i] = leds[i+1];
        }
        leds[NUM_LEDS - 1] = buff[dwmIterator];
        accumulateMeasurementsForDwm();
        FastLED.show();
        
        dwmIterator++;
        if (dwmIterator == MAX_WIDTH){
          dwmMode = 2;
          dwmIterator = 0;
        }
        break;
      } 
  
      // Write buffer black leds in order to create some gap between outputs
      case 2:{
        for(int i = 0; i < (NUM_LEDS - 1); i++){
           leds[i] = leds[i+1];
        }
        leds[NUM_LEDS - 1] = CRGB::Black;
        FastLED.show();
        accumulateMeasurementsForDwm();
        
        dwmIterator++;
        if (dwmIterator == EMPTY_WIDTH){
          dwmMode = 0;
          dwmIterator = 0;
        }  
        break;
      }
      default:
        ;
      
    }
  prevDropTime = millis();
  }
}

void pwmVu(){
  if (measurementRes >= ledLevel){
    ledLevel = measurementRes;
  }

  else{
    if ( ( (millis() - prewDecayTime) >= DECAY_INTERVAL ) && ledLevel>(measurementRes)){
      ledLevel--;
      prewDecayTime = millis();
    }
  }

  for(int i = 0; i < NUM_LEDS; i++){
    leds[i].r = filled[i].r*ledLevel/NUM_LEDS;
    leds[i].g = filled[i].g*ledLevel/NUM_LEDS;
    leds[i].b = filled[i].b*ledLevel/NUM_LEDS;
  }
  
  if(indicateSeconds)
    leds[(millis()/1000)%NUM_LEDS] = secsIndicatorCol;
    
  FastLED.show();
}

void drawVuFast(){
  FastLED.clear();
  for(int i=0; i < measurementRes; i++){
    leds[i] = filled[i];
  }
  if(indicateSeconds)
    leds[(millis()/1000)%NUM_LEDS] = secsIndicatorCol;
  FastLED.show();
}

void animatedFlag(int which){
  uint16_t sinBeat = beatsin16(30, 0, NUM_LEDS - 1, 0, 0);
  uint16_t sinBeat2 = beatsin16(30, 0, NUM_LEDS - 1, 0, 32767);
  uint16_t sinBeat3 = beatsin16(30, 0, NUM_LEDS - 1, 0, 0);
  uint16_t sinBeat4 = beatsin16(30, 0, NUM_LEDS - 1, 0, 21845);
  uint16_t sinBeat5 = beatsin16(30, 0, NUM_LEDS - 1, 0, 43690);
  switch(which){
    case 16:
      leds[sinBeat] = CRGB::White;
      leds[sinBeat2] = CRGB::Red;
      fadeToBlackBy(leds, NUM_LEDS, 10);
      FastLED.show();
      break;
    case 17:
      leds[sinBeat3] = CRGB::Green;
      leds[sinBeat4] = CRGB::Red;
      leds[sinBeat5] = CRGB::Cyan;
      fadeToBlackBy(leds, NUM_LEDS, 10);
      FastLED.show();
      break;
  default:
  ;
  }
}

void torch(CRGB color){
  fill_solid(leds, NUM_LEDS, color);
  if(indicateSeconds)
    leds[(millis()/1000)%NUM_LEDS] = secsIndicatorCol;
  FastLED.show();
}

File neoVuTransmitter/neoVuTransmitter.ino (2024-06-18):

      /******** References *********/
/* 
 *  ============= AP ============= 
 *  https://github.com/esp8266/Arduino/blob/master/doc/esp8266wifi/soft-access-point-class.rst
 *  
 *  ============= UDP ============= 
 * https://siytek.com/communication-between-two-esp8266/
 * https://stackoverflow.com/questions/39064193/esp8266-send-udp-string-to-ap
 * https://www.tutorialspoint.com/c_standard_library/c_function_strtok.htm
 * 
 * ============= OLED Display ============= 
 * https://www.instructables.com/OLED-I2C-Display-ArduinoNodeMCU-Tutorial/
 * https://www.circuitgeeks.com/oled-display-arduino/
 * https://learn.adafruit.com/adafruit-gfx-graphics-library/using-fonts
 * https://learn.adafruit.com/adafruit-gfx-graphics-library/graphics-primitives
 * https://oleddisplay.squix.ch/#/home // Font generator
 * 
 * ============= Rotary Encoder =============
 * See the link below for extra info
 * https://lastminuteengineers.com/rotary-encoder-arduino-tutorial/
 * https://dronebotworkshop.com/rotary-encoders-arduino/
 * 
 * ============= External i2c EEPROM =============
 * External EEPROM reading-writing functions are adopted from the link below:
 * https://dronebotworkshop.com/eeprom-arduino/
 * https://arduino-projects4u.com/arduino-24c16/
 * 
*/
#define DEBUG_ENABLED false
#define UART_DATA_MESSAGE_BAUDRATE 115200

/* Libraries */
#include <ESP8266WiFi.h>
#include <WiFiUdp.h>

#include <Wire.h>
#include <Adafruit_GFX.h>
#include <Adafruit_SSD1306.h>
#include <Fonts\FreeSans18pt7b.h>
#include <Fonts\FreeSans12pt7b.h>

#include <SoftwareI2C.h>

/* My files */
#include "secrets.h"
#include "dialog13.h"
#include "dialog11.h"
#include "dialog9.h"

/******** Constants *********/
#define PACKET_BUFFER_SIZE 255
#define MODE_NUM 18
#define MENU_COUNT 10

/* OLED Display */
#define SCREEN_WIDTH 128
#define SCREEN_HEIGHT 64 
#define OLED_RESET -1
#define SCREEN_ADDRESS 0x3C

/* External i2c EEPROM */
#define EEPROM_ADDR 0x50
#define EEPROM_SCL D4
#define EEPROM_SDA D5
#define EEPROM_TYPE "24C08" // The other model I have tested is "24C32"

/* Rotary Encoder */
#define ROTARY_CLK D6
#define ROTARY_DT D7
#define ROTARY_BTN D3

/* Measurements */
#define MUSIC A0
#define NUM_MEASUREMENTS 15

/* Serial communication */
#define DEBUG_RATE 9600 // Baud rate to print debug info to computer

/******** Function templates ********/
void ICACHE_RAM_ATTR checkRotary();
void ICACHE_RAM_ATTR handleBtn();

/******** Global variables & objects ********/
/* UDP */
WiFiUDP UDP; // creating UDP object
char packetBuffer[PACKET_BUFFER_SIZE]; // UDP Buffer

/* OLED Display */
String titles[MENU_COUNT] = {"Brightness", "Mode", "Sensivity", "Threshold", "Music Indicator", "Second Indicator", "Wifi Channel*", "Source", "Save Config.", "Restart"};
bool titleOrValue = 0; // 0: title selected, 1: value selected
int counter = 0; // titleIndex_x2
int titleIndex = 0;
int varArr_x2[MENU_COUNT - 2] = {511, 0, 8, 20, 2, 2, 2, 0}; // int brightness_x2 = 511, vuMode_x2 = 0, sensivity_x2 = 8, threshold_x2 = 20, bool musicInd_x2 = 2; secsInd_x2 = 2; WifiChannel_x2 = 22; Source_x2 = 0;
uint8_t varArr[MENU_COUNT - 2] = {255, 0, 4, 10, 1, 1, 1,  0}; // uint8_t brightness = 255, vuMode = 0, sensivity = 4, threshold = 10,  bool musicInd = 1, bool secsInd = 1; WifiChannel = 11; Source = 0;
String varRangeLimMin[MENU_COUNT] = {"0", "0", "0", "0", "0", "0", "1", "0", "0", "0"};
String varRangeLimMax[MENU_COUNT] = {"255", String(MODE_NUM-1), "255", "255", "1", "1", "13", "1", "0", "0"};
String boolArr[] = {"disabled", "enabled"};
String saSources[] = {"analog", "serial"};
Adafruit_SSD1306 display(SCREEN_WIDTH, SCREEN_HEIGHT, &Wire, OLED_RESET);
byte displayUpdateIterCou = 0;

/* Serial Comm */
uint8_t ui8ReceivedAmplitudeInBits = 0;

/* Rotary Encoder */
int currentStateCLK;
int previousStateCLK; 

/* External i2c EEPROM */
bool configWillBeSaved = false;
SoftwareI2C softwarei2c;

/* General */
bool goingToRestart = false;

/******** Functions ********/

void(* resetFunc) (void) = 0; // when you call it, it resets the board

void restart_(){
  display.clearDisplay();
  display.fillRect(0, 0, 128, 16, WHITE);
  display.setFont(&Dialog_plain_13);
  display.setCursor(1, 12);
  display.setTextColor(BLACK); // 'inverted' text
  display.println("Please wait...");
  display.setCursor(1, 25);
  display.setFont(&Dialog_plain_11);
  display.setTextColor(WHITE);
  display.println("Device will restart in 2 seconds");
  display.display();
  
  delay(2000);

  resetFunc();
}

void normalizeVars(){
  for(int i = 0; i<(MENU_COUNT - 2); i++){
    varArr[i] = (uint8_t) (varArr_x2[i]/2);
  }

  // Normalizing "Mode" variable
  //varArr[1] %= MODE_NUM;
  if (varArr[1] == 255){ // i.e. varArr[1] < 0 if it were not uint8_t
    varArr[1] = MODE_NUM - 1;
    varArr_x2[1] = 2*(MODE_NUM - 1);
  }
  else if (varArr[1] > (MODE_NUM - 1)){
    varArr[1] = 0;
    varArr_x2[1] = 0;
  }
  
  varArr[4] = (varArr[4] % 2); // In fact, music indicator is a bool so scale it to be bool
  varArr[5] = (varArr[5] % 2); // In fact, indicate seconds is a bool so scale it to be bool

  // Channel can be only in between [1-13]
  if (varArr[6] < 1){
    varArr[6] = 13;
    varArr_x2[6] = 26;
  }
  else if (varArr[6] > 13){
    varArr[6] = 1;
    varArr_x2[6] = 2;
  }

  varArr[7] = (varArr[7] % 2); // In fact, input  is a bool so scale it to be bool
 
}

void enableInterrupts(){
  attachInterrupt(digitalPinToInterrupt(ROTARY_CLK), checkRotary, CHANGE);
  attachInterrupt(digitalPinToInterrupt(ROTARY_DT), checkRotary, CHANGE);
  attachInterrupt(digitalPinToInterrupt(ROTARY_BTN), handleBtn, FALLING);
}

void disableInterrupts(){
  detachInterrupt(digitalPinToInterrupt(ROTARY_CLK) );
  detachInterrupt(digitalPinToInterrupt(ROTARY_DT) );
  detachInterrupt(digitalPinToInterrupt(ROTARY_BTN) );
}

void initRotary() { 
  pinMode(ROTARY_CLK,INPUT);
  pinMode(ROTARY_DT,INPUT);
  pinMode(ROTARY_BTN, INPUT_PULLUP);
  previousStateCLK = digitalRead(ROTARY_CLK);  
}
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

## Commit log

2021-10-17 Add files via upload
    Fixed error. There is a 330 Ohm resistor between LED DIN pin and ESP D2 pin
2021-11-07 Bugfixes and feature updates
    - Displayed range is always [0-255] bug is fixed.
    - Added restart future to the menu.
    - Added wi-fi channel change feature to the menu. (After changing the channel, first, you have to save the config and then restart in order to new setting to be valid)
    [neoVuTransmitter.ino]
2021-11-07 Optimization and a potential bug's fix.
    Some loop limits have been changed.
    [neoVuTransmitter.ino]
2022-02-13 Feature update & bugfix
    - Added two more color schemes
    - Fixed the bug in the "mode" section: The normalisation process was wrong
    [neoVuReceiver.ino, neoVuTransmitter.ino]
2022-02-13 Fixed typo in schematic
    -The value for the capacitor must be 100nF. It was drawn that 100uF accidentally.
